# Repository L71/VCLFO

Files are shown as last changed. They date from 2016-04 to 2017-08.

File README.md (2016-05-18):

VCLFO
=====

This is an LFO/oscillator with voltage control (uses LED+LDR circuit for F control).
Built-in attenuverter for frequency CV input. Outputs for triangle/saw + square wave. Three frequency ranges, sloooow to mid audio range.

Version 2 works better, it has exponential frequency response (don't expect it to be linear or precise, though!) and the LED will work corectly when in ramp output mode. 
The trimmer pot on the V. 2 can be used to tune the LFO rate ranges. The correct setting should be when it's at about 5-6 kOhm (the exponential converter output should just about reach the maximum negative voltage when the rate pot is at maximum). 

Panels and PCBs licensed cc-by-sa.

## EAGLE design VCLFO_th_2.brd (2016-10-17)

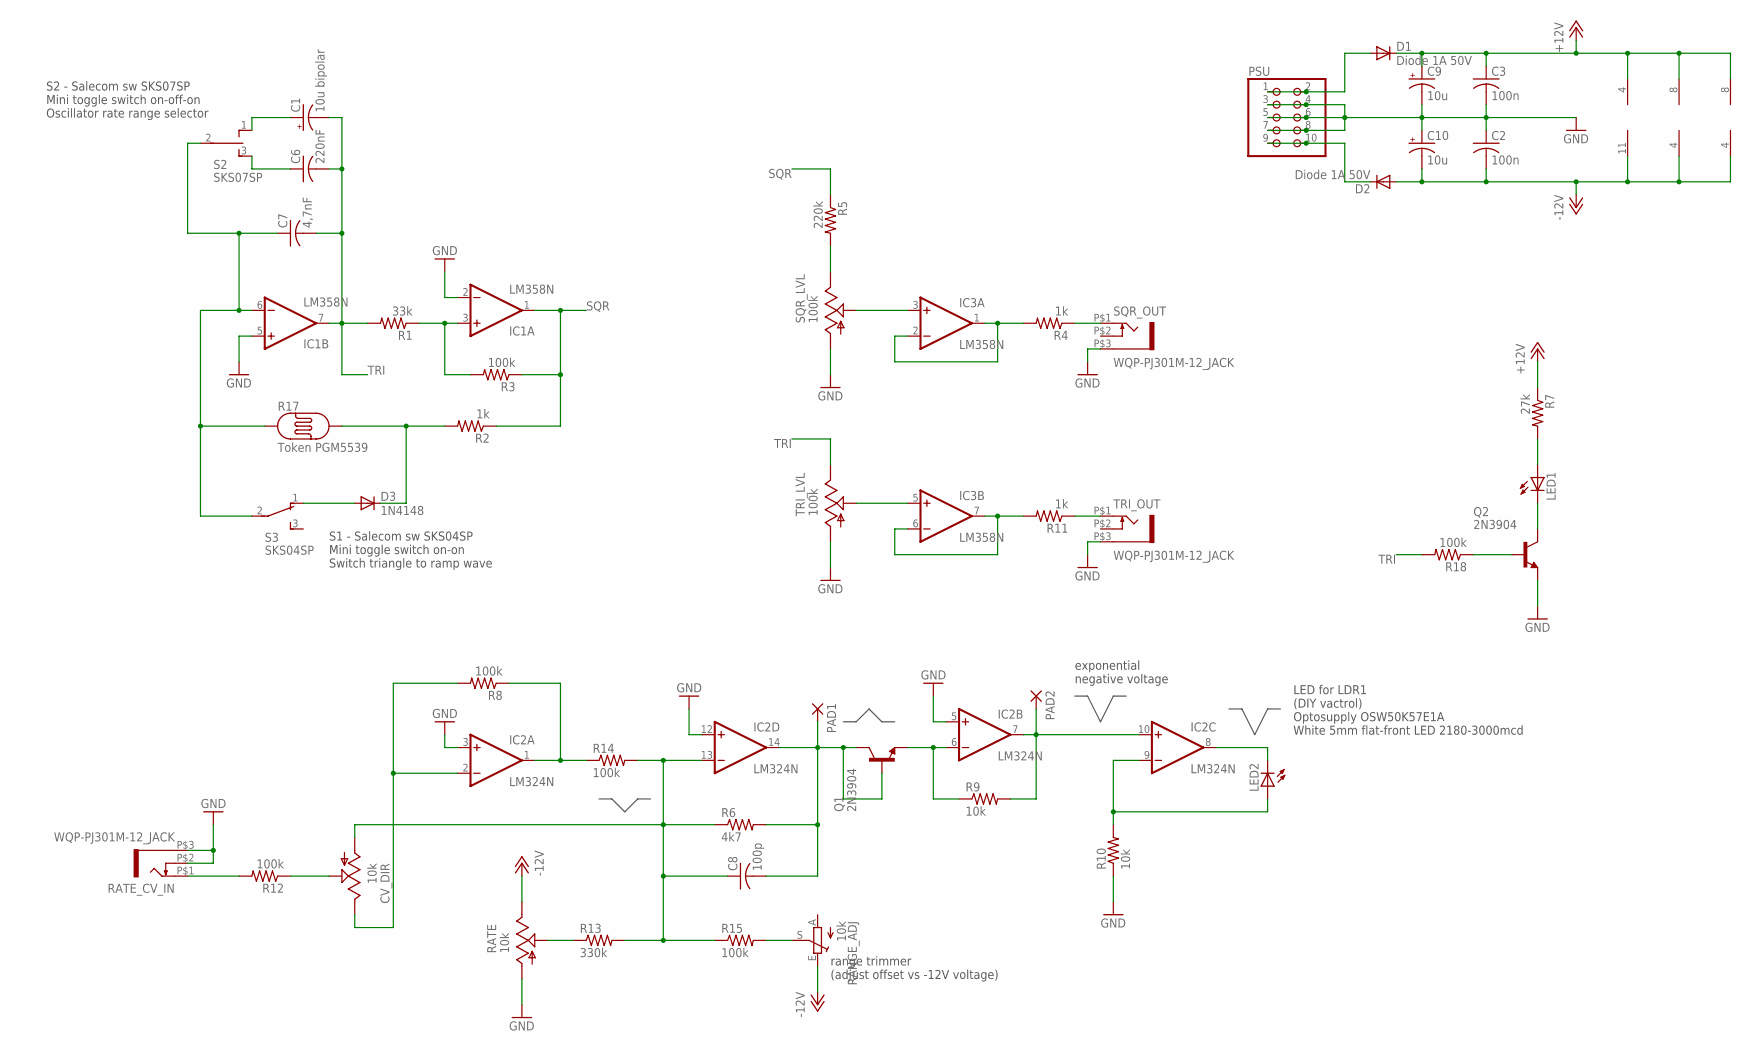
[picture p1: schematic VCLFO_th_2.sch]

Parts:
C1: 10u bipolar; E2,5-5
C2, C3: 100n; C025-025X050
C6: 220nF; C050-025X075
C7: 4,7nF; C025-025X050
C8: 100p; C025-025X050
C9, C10: 10u; E2,5-5
CV_DIR: 10k; ALPS_POT_VERTICAL
D1, D2: Diode 1A 50V; D-2.5
D3: 1N4148; D-5
IC1, IC3: LM358N; DIL08
IC2: LM324N; DIL14
LED1, LED2: LED5MM
PAD1, PAD2: 1,6/0,8
PSU: PINHD-2X5; 2X05
Q1, Q2: 2N3904; TO92
R1: 33k; 0204V
R2, R4, R11: 1k; 0204V
R3, R8, R12, R14, R15, R18: 100k; 0204V
R5: 220k; 0204V
R6: 4k7; 0204V
R7: 27k; 0204V
R9, R10: 10k; 0204V
R13: 330k; 0204V
R17: Token PGM5539; PHOTOCELL
RANGE_ADJ: 10k; B25P
RATE: 10k; ALPS_POT_VERTICAL
RATE_CV_IN: WQP-PJ301M-12_JACK
S2: SKS07SP; TL3XPO
S3: SKS04SP; TL3XPO
SQR_LVL: 100k; ALPS_POT_VERTICAL
SQR_OUT: WQP-PJ301M-12_JACK
TRI_LVL: 100k; ALPS_POT_VERTICAL
TRI_OUT: WQP-PJ301M-12_JACK

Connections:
+12V: C3.1, C9.+, D1.C, IC1.8 (V+), IC2.4 (V+), IC3.8 (V+), R7.1
-12V: C2.2, C10.-, D2.A, IC1.4 (V-), IC2.11 (V-), IC3.4 (V-), RANGE_ADJ.E, RATE.P$1 (E)
GND: C2.1, C3.2, C9.-, C10.+, IC1.2 (-IN), IC1.5 (+IN), IC2.3 (+IN), IC2.5 (+IN), IC2.12 (+IN), PSU.3, PSU.4, PSU.5, PSU.6, PSU.7, PSU.8, Q2.3 (E), R10.1, RATE.P$3 (A), RATE_CV_IN.P$2 (3), RATE_CV_IN.P$3 (1), SQR_LVL.P$3 (A), SQR_OUT.P$3 (1), TRI_LVL.P$3 (A), TRI_OUT.P$3 (1)
unnamed: C7.1, IC1.6 (-IN), R17.1, S2.2, S3.2
unnamed: D3.C, R2.2, R17.2
unnamed: IC3.1 (OUT), IC3.2 (-IN), R4.2
unnamed: R5.2, SQR_LVL.P$1 (E)
unnamed: IC1.3 (+IN), R1.1, R3.2
unnamed: R4.1, SQR_OUT.P$1 (2)
unnamed: CV_DIR.P$1 (E), IC2.2 (-IN), R8.2
unnamed: IC3.6 (-IN), IC3.7 (OUT), R11.2
unnamed: IC3.3 (+IN), SQR_LVL.P$2 (S)
unnamed: D1.A, PSU.1, PSU.2
unnamed: D2.C, PSU.9, PSU.10
unnamed: R12.2, RATE_CV_IN.P$1 (2)
unnamed: C8.2, IC2.14 (OUT), PAD1.1, Q1.1 (C), Q1.2 (B), R6.2
unnamed: C1.+, S2.1 (O)
unnamed: CV_DIR.P$2 (S), R12.1
unnamed: D3.A, S3.1 (O)
unnamed: R11.1, TRI_OUT.P$1 (2)
unnamed: R13.1, RATE.P$2 (S)
unnamed: C6.1, S2.3 (S)
unnamed: Q2.2 (B), R18.1
unnamed: IC2.6 (-IN), Q1.3 (E), R9.1
unnamed: IC2.1 (OUT), R8.1, R14.1
unnamed: C8.1, CV_DIR.P$3 (A), IC2.13 (-IN), R6.1, R13.2, R14.2, R15.1
unnamed: IC2.7 (OUT), IC2.10 (+IN), PAD2.1, R9.2
unnamed: R15.2, RANGE_ADJ.S
unnamed: IC2.8 (OUT), LED2.K (C)
unnamed: IC2.9 (-IN), LED2.A, R10.2
unnamed: IC3.5 (+IN), TRI_LVL.P$2 (S)
unnamed: LED1.K (C), Q2.1 (C)
unnamed: LED1.A, R7.2
SQR: IC1.1 (OUT), R2.1, R3.1, R5.1
TRI: C1.-, C6.2, C7.2, IC1.7 (OUT), R1.2, R18.2, TRI_LVL.P$1 (E)

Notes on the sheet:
S1 - Salecom sw SKS04SP Mini toggle switch on-on Switch triangle to ramp wave
LED for LDR1 (DIY vactrol) Optosupply OSW50K57E1A White 5mm flat-front LED 2180-3000mcd
S2 - Salecom sw SKS07SP Mini toggle switch on-off-on Oscillator rate range selector
range trimmer (adjust offset vs -12V voltage)
exponential negative voltage

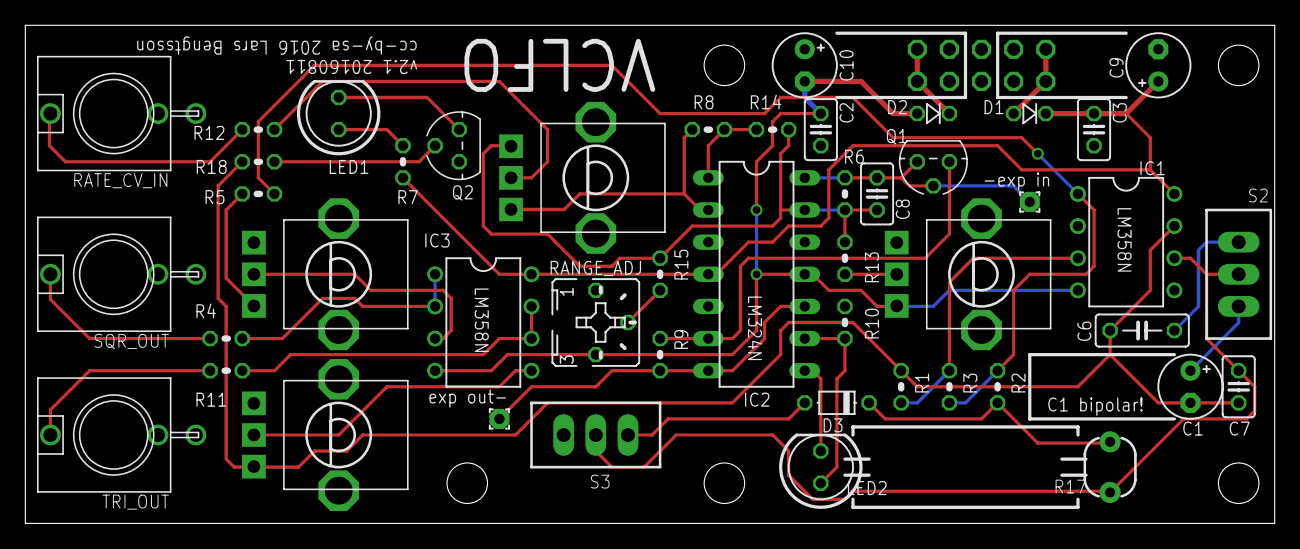
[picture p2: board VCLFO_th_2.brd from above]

Board: 2 copper layers, 98.7 x 39.4 mm, 48 parts (1 on the bottom side), 35 nets.

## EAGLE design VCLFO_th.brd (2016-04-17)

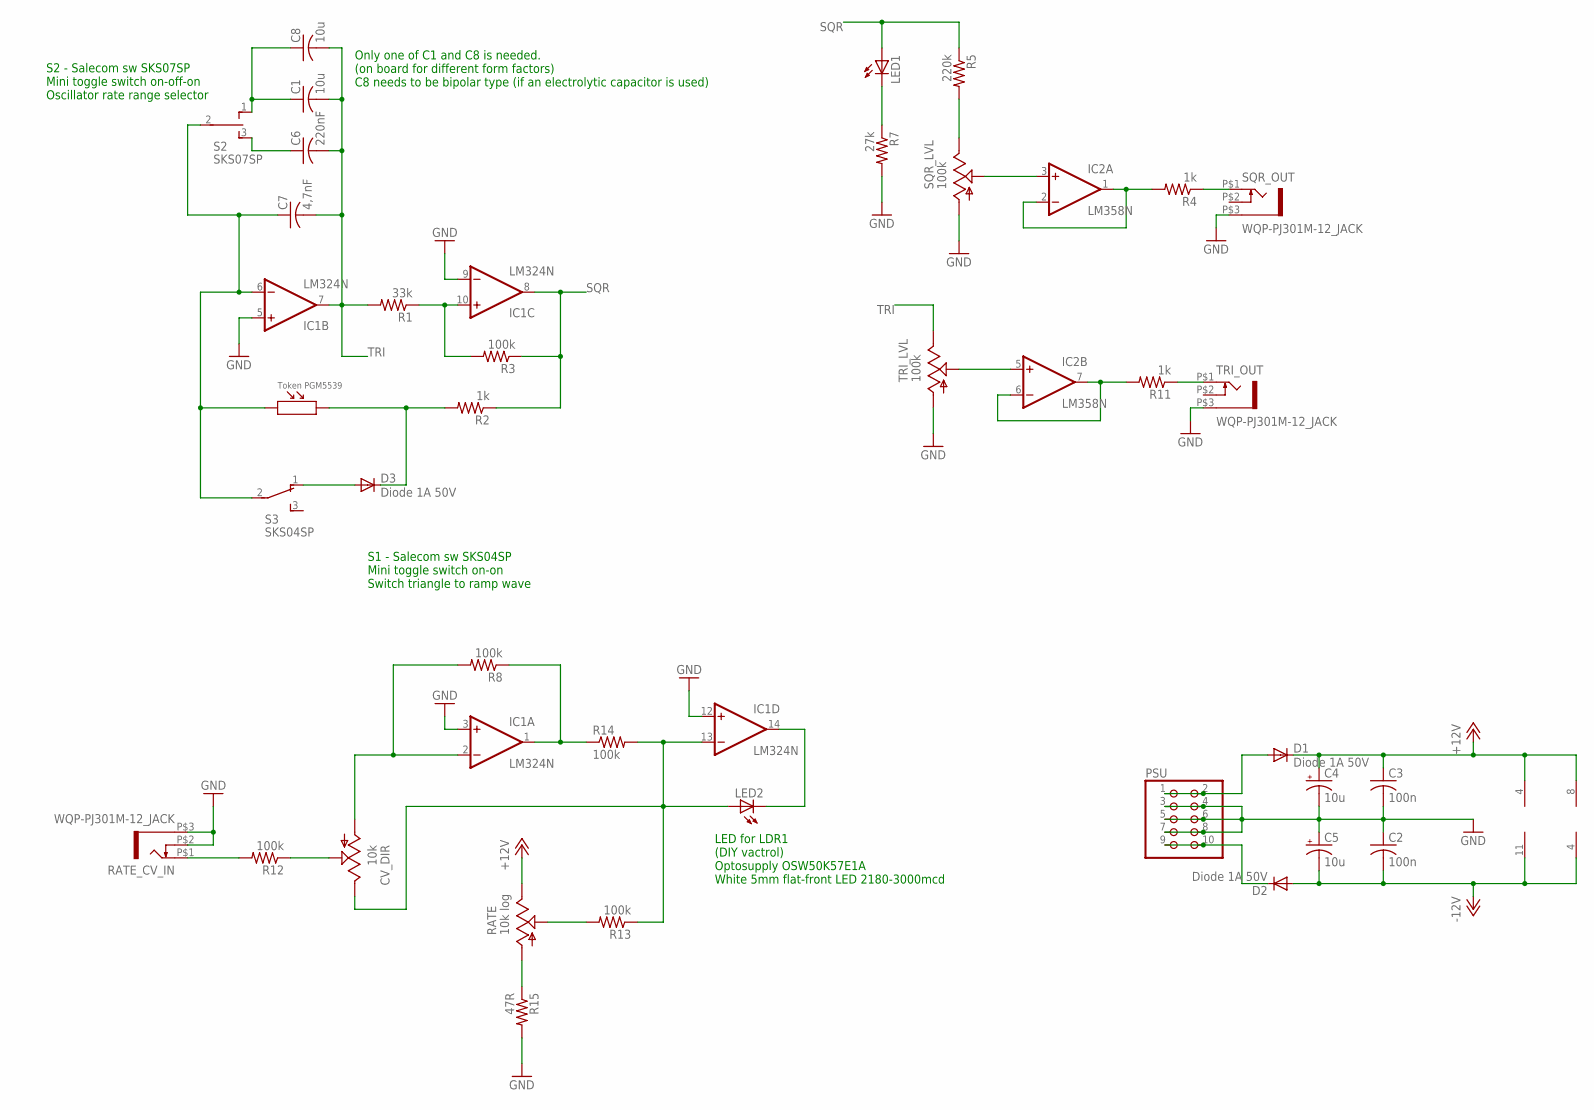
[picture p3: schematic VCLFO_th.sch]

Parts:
C1: 10u; C1206
C2, C3: 100n; C025-025X050
C4, C5: 10u; E2,5-6
C6: 220nF; C025-025X050
C7: 4,7nF; C025-025X050
C8: 10u; C025-050X050
CV_DIR: 10k; ALPS_POT_VERTICAL
D1, D2, D3: Diode 1A 50V; D-5
IC1: LM324N; DIL14
IC2: LM358N; DIL08
LDR1: Token PGM5539; LDR_SNR2-3.0
LED1: LED5MM
LED2: LED3MM
PSU: PINHD-2X5; 2X05
R1: 33k; 0207/2V
R2, R4, R11: 1k; 0207/2V
R3, R8, R12, R13, R14: 100k; 0207/2V
R5: 220k; 0207/2V
R7: 27k; 0207/2V
R15: 47R; 0207/2V
RATE: 10k log; ALPS_POT_VERTICAL
RATE_CV_IN: WQP-PJ301M-12_JACK
S2: SKS07SP; TL3XPO
S3: SKS04SP; TL3XPO
SQR_LVL: 100k; ALPS_POT_VERTICAL
SQR_OUT: WQP-PJ301M-12_JACK
TRI_LVL: 100k; ALPS_POT_VERTICAL
TRI_OUT: WQP-PJ301M-12_JACK

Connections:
+12V: C3.1, C4.+, D1.C, IC1.4 (V+), IC2.8 (V+), RATE.P$1 (E)
-12V: C2.2, C5.-, D2.A, IC1.11 (V-), IC2.4 (V-)
GND: C2.1, C3.2, C4.-, C5.+, IC1.3 (+IN), IC1.5 (+IN), IC1.9 (-IN), IC1.12 (+IN), PSU.3, PSU.4, PSU.5, PSU.6, PSU.7, PSU.8, R7.2, R15.2, RATE_CV_IN.P$2 (3), RATE_CV_IN.P$3 (1), SQR_LVL.P$3 (A), SQR_OUT.P$3 (1), TRI_LVL.P$3 (A), TRI_OUT.P$3 (1)
unnamed: C7.1, IC1.6 (-IN), LDR1.1, S2.2, S3.2
unnamed: LED1.K (C), R7.1
unnamed: IC2.1 (OUT), IC2.2 (-IN), R4.2
unnamed: R5.2, SQR_LVL.P$1 (E)
unnamed: IC1.10 (+IN), R1.1, R3.2
unnamed: R4.1, SQR_OUT.P$1 (2)
unnamed: D3.C, LDR1.2, R2.2
unnamed: IC2.6 (-IN), IC2.7 (OUT), R11.2
unnamed: IC2.3 (+IN), SQR_LVL.P$2 (S)
unnamed: D1.A, PSU.1, PSU.2
unnamed: D2.C, PSU.9, PSU.10
unnamed: R12.2, RATE_CV_IN.P$1 (2)
unnamed: C1.1, C8.1, S2.1 (O)
unnamed: CV_DIR.P$2 (S), R12.1
unnamed: D3.A, S3.1 (O)
unnamed: R11.1, TRI_OUT.P$1 (2)
unnamed: C6.1, S2.3 (S)
unnamed: CV_DIR.P$3 (A), IC1.2 (-IN), R8.2
unnamed: IC1.14 (OUT), LED2.K (C)
unnamed: IC1.1 (OUT), R8.1, R14.1
unnamed: CV_DIR.P$1 (E), IC1.13 (-IN), LED2.A, R13.1, R14.2
unnamed: R13.2, RATE.P$2 (S)
unnamed: R15.1, RATE.P$3 (A)
unnamed: IC2.5 (+IN), TRI_LVL.P$2 (S)
SQR: IC1.8 (OUT), LED1.A, R2.1, R3.1, R5.1
TRI: C1.2, C6.2, C7.2, C8.2, IC1.7 (OUT), R1.2, TRI_LVL.P$1 (E)

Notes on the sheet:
S1 - Salecom sw SKS04SP Mini toggle switch on-on Switch triangle to ramp wave
LED for LDR1 (DIY vactrol) Optosupply OSW50K57E1A White 5mm flat-front LED 2180-3000mcd
S2 - Salecom sw SKS07SP Mini toggle switch on-off-on Oscillator rate range selector
Only one of C1 and C8 is needed. (on board for different form factors) C8 needs to be bipolar type (if an electrolytic capacitor is used)

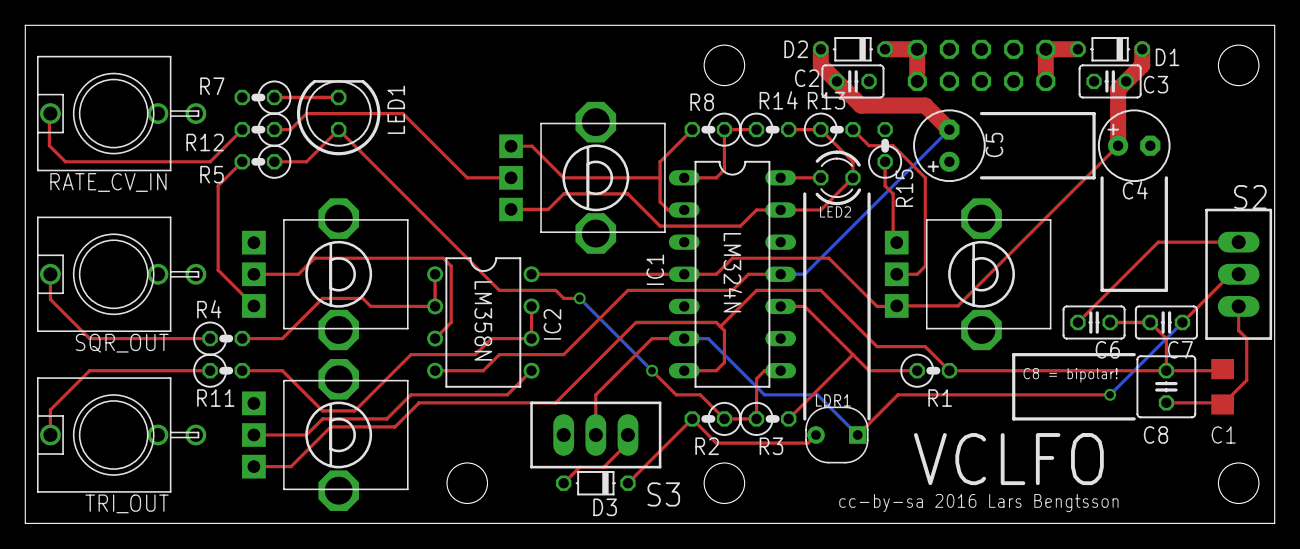
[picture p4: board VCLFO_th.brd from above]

Board: 2 copper layers, 98.7 x 39.4 mm, 38 parts (1 on the bottom side), 29 nets.

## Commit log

2016-03-28 Initial upload.
    [VCLFO_th.brd, VCLFO_th.sch]
2016-03-28 Updated component values of LED2 and LDR1 (Vactrol/optocoupler).
    [VCLFO_th.brd, VCLFO_th.sch]
2016-03-29 Added comment about C1/C8.
    [VCLFO_th.sch]
2016-04-17 Renamed IC3->IC2. Rate CV potentiometer was 1/40" off, corrected. Moved IC1 1/40" towards same pot, makes a bit more space for optical stuff. Moved R15 a bit, moved C6 and C7.
    [VCLFO_th.brd, VCLFO_th.sch]
2016-04-17 Minor updates to labels.
    [VCLFO_th.brd]
2016-05-16 Initial add, version with exponential converter for rate control voltage.
    [VCLFO_th_2.brd, VCLFO_th_2.sch]
2016-08-11 Fixed circuit around timer vactrol (bypass diode for saw wave works better at high rates). Changed biggest timer cap + the bigger PSU caps from 1206 to TH electrolytics. Rerouted accordingly.
    [VCLFO_th_2.brd, VCLFO_th_2.sch]
2016-10-17 Removed ledftover label on back of PCB. Changed footprint for vactrol LED to 5mm (easier to see polarity after manufacturing).
    [VCLFO_th_2.brd, VCLFO_th_2.sch]
2017-08-26 Added PCB front panel. (not yet tested)
    [VCLFO-1.0-PCB-panel.brd]

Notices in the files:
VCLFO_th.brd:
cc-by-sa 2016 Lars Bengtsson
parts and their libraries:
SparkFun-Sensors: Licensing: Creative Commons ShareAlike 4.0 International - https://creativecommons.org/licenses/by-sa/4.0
